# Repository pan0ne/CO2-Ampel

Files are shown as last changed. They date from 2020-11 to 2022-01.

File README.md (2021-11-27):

# DIY CO2-Messgerät / CO2-Ampel

Dieses Projekt zeigt den Bau einer CO2-Ampel.
Als Basis benutze ich einen **ESP8266 / ESP32 Mikrocontroller** und ein **MHZ-19b CO2-Sensor**. Zusätzlich kann ein **BME680 Luftqualitätssensor** angeschlossen werden, um die Messwerte zu präzisieren sowie **Neopixel (WS2812b)** und/oder ein **SSD1306 Display** zur visuellen Anzeige.  

**Messdaten**
- **Temperatur (C)**
- **Luftfeuchtigkeit (%)**
- **CO2 (ppm)**,
- **Luftdruck (hPa)**
- **Luftqualität (VOC, flüchtige organische Verbindungen)**.

Die **Sensordaten** können via **LoRa WAN** an das **thethingsnetwork.org** gesendet werden oder direkt per **WiFi**.
Zur **Analyse der Daten** werden diese an **thingsspeak.com** übertragen und grafisch aufbereitet. (Account nötig)
Bis auf den CO2-Sensor, der mit 5V betrieben wird, reicht für alles andere 3.3V. Der CO2-Sensor wird seriell über die RX/TX Pins abgefragt. Der Luftqualitätssensor kommuniziert über den i2c bus.

**Gehäuse**
- **Design**: TinkerCad.com
- **Download (.stl Format)**:
https://www.thingiverse.com/thing:4644826
- **Material**:   PLA (Sunlu), Holzoptik, carbonschwarz, transparent
- **Temperatur**: 195°C Noozle / Heizbett 58°
- **Einstellungen**: keine Stützstrukturen
- **Slicer**: Cura 4.x.x

**Bauanleitung**

Eine ***Bauanleitung*** mit allen Angaben von Druck der Bauteile über Verkabelung bis Programmierung befindet sich ***im Github Wiki***:

- https://github.com/pan0ne/CO2-Ampel/wiki/Home

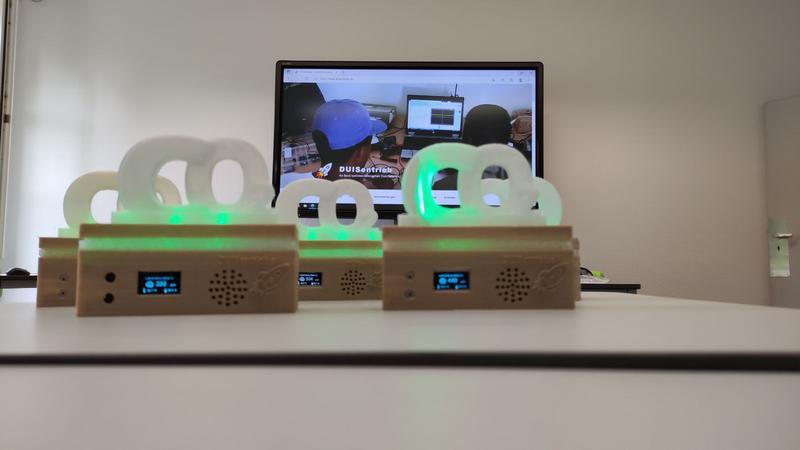
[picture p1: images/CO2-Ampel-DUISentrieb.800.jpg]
Verwendete Werkzeuge


[Weitere Fotos in der Galerie auf Thingiverse](https://www.thingiverse.com/thing:4644826)

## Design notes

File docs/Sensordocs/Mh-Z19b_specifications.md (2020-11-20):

**The MH-Z19B carbon dioxide gas sensor**

*Parameters:*

Product Model Number: MH-Z19B

Gas detection: carbon dioxide

Supply voltage: 4.5 ~ 5.5 V DC

Average current: <20mA (at 5V power supply)

Peak current: 150 mA (at 5 V supply)

Interface Level: 3.3V (5V compatible)

Measuring range: 0 ~ 10000ppm can be selected within the range

Warm-up time: 3 minutes

Response time: T90 <120s

Working temperature: 0 - 50 °C

Humidity: 0 to 95% RF (non-condensing)

Vin: positive power (Vin)

GND: Negative power supply (GND)

VO: Analog output

PWM: PWM

HD: HD (zero for school, low for more than 7 seconds)

Rx: TTL level data input for UART (RXD)

Tx: TTL data output with UART (TXD) level

Pin 1: Analogue output from

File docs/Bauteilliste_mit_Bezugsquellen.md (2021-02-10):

##Elektronische Bauteile / Einkaufsliste##

**Heltec Wifi LoRa v2 Microcontriller (ESP32)**
- Boardinformationen: https://heltec.org/project/wifi-lora-32/ 
- incl. Display SSD1306 (128x64, OLED), I2C 
- Quelle: https://www.az-delivery.de/products/nodemcu-esp32-mit-integrierten-oled-display?_pos=2&_sid=3fde67778&_ss=r (33.99€ DE Versand)

**Wifi Version ohne LoRaWAN**:
 - https://www.az-delivery.de/products/nodemcu (5,99€)
 - Display: https://www.conrad.de/de/p/joy-it-sbc-oled01-display-modul-2-4-cm-0-96-zoll-128-x-64-pixel-2176922.html (6,99€)

**Bosch BlueDot BME680 (Temp, VOC, Humidity, Air Pressure), I2C**
- https://www.bluedot.space/sensor-boards/bme680/
- Quelle: https://www.exp-tech.de/sensoren/temperatur/8371/bluedot-bme680-breakout-board-temperatur-feuchte-luftdruck-und-gas (21,40€ DE Versand)

- **Alternative BME680 (CJMCU) Sensor:** 
 - https://www.banggood.com/CJMCU-680-BME680-BOSCH-Temperature-And-Humidity-Pressure-Sensor-p-1268323.html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 (ca. 10€)
 - 
 
**MH-Z19B CO2 Sensor (RX, TX), Serial**
- Docs: https://www.winsen-sensor.com/d/files/infrared-gas-sensor/mh-z19b-co2-ver1_0.pdf
- Quelle: https://www.reichelt.de/infrarot-co2-sensor-mh-z19b-co2-mh-z19b-p266033.html (27,00€, Articel: CO2 MH-Z19B)
- Quelle: https://www.banggood.com/MH-Z19-MH-Z19B-Infrared-CO2-Sensor-Module-Carbon-Dioxide-Gas-Sensor-for-CO2-Monitor-0-5000ppm-MH-Z19B-NDIR-with-Pin-p-1693604.html (23€)

**Neopixel LED 1m Strip**
- Quelle: https://www.conrad.de/de/p/makerfactory-m5stack-neopixel-strip-mf-6324765-led-streifen-mit-stecker-buchse-3-5-v-526-mm-tape-cut-2108255.html (19,49€, Article: 2108255 - 62, DE Verkauf)
- Quelle (die günstige Variante): https://de.banggood.com/1M-WS2812-IC-SMD5050-Dream-Color-RGB-Non-Waterproof-LED-Strip-Light-Individual-Addressable-DC5V-p-1139749.html?ID=224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 (5,12€, Versand aus China oder Spanien) 
Quelle: https://www.banggood.com/4-PCS-PandaRC-5V-RGB-WS2812-LED-Strip-w-or-100mm-Cable-for-F3-F4-Flight-Controller-RC-Drone-FPV-Racing-p-1672588.html
(6€)
- https://www.banggood.com/Lantian-2-in-1-WS2812B-LED-And-5V-Active-Buzzer-For-FPV-NAZE32-Skyline32-Flight-Controller-p-1012950.html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
(8 x WS2812B LED And 5V Active Buzzer, ca 4€)

Sicher können hier auch andere Neopixelvarianten benutzt werden. Es gibt kleine 8 Pixelstreifen auch für 3 €uro im Netz zu finden.

**Batterie Modul 18650 V3 inkl. USB Kabel**
- Quelle (die günstige Variante): https://de.banggood.com/ESP32S-ESP32-0_5A-Micro-USB-Charger-Board-18650-Battery-Charging-Shield-without-Battery-p-1395271.html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 (3,24€ UK Versand)
- Quelle:  https://www.az-delivery.de/products/battery-expansion-shield-18650-v3-inkl-usb-kabel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 (7,47€ DE Verkauf)

**DuPont Cable with Connector (2x4Wire, 1x3Wire), Power Connector Cable for Heltec Microcontroller**
- Jumper Wire Kabel 40 STK. je 20 cm F2F Female to Female, Male-Female für Arduino und Raspberry Pi Breadboard
- https://www.az-delivery.de/products/40-stk-jumper-wire?_pos=9&_sid=12ce6cb8d&_ss=r (3,66€ DE Versand) 

**Gesamtkosten :  ca. 113€** (Shops innerhalb Europas)

**(direkt aus CN, Banggood, AliExpress oder Amazon Import: ~85,00€)**

**(Alternative Version: ESP8266: ~60,00€)**

**(direkt aus CN, Banggood, AliExpress oder Amazon Import: 40 - 50€)**

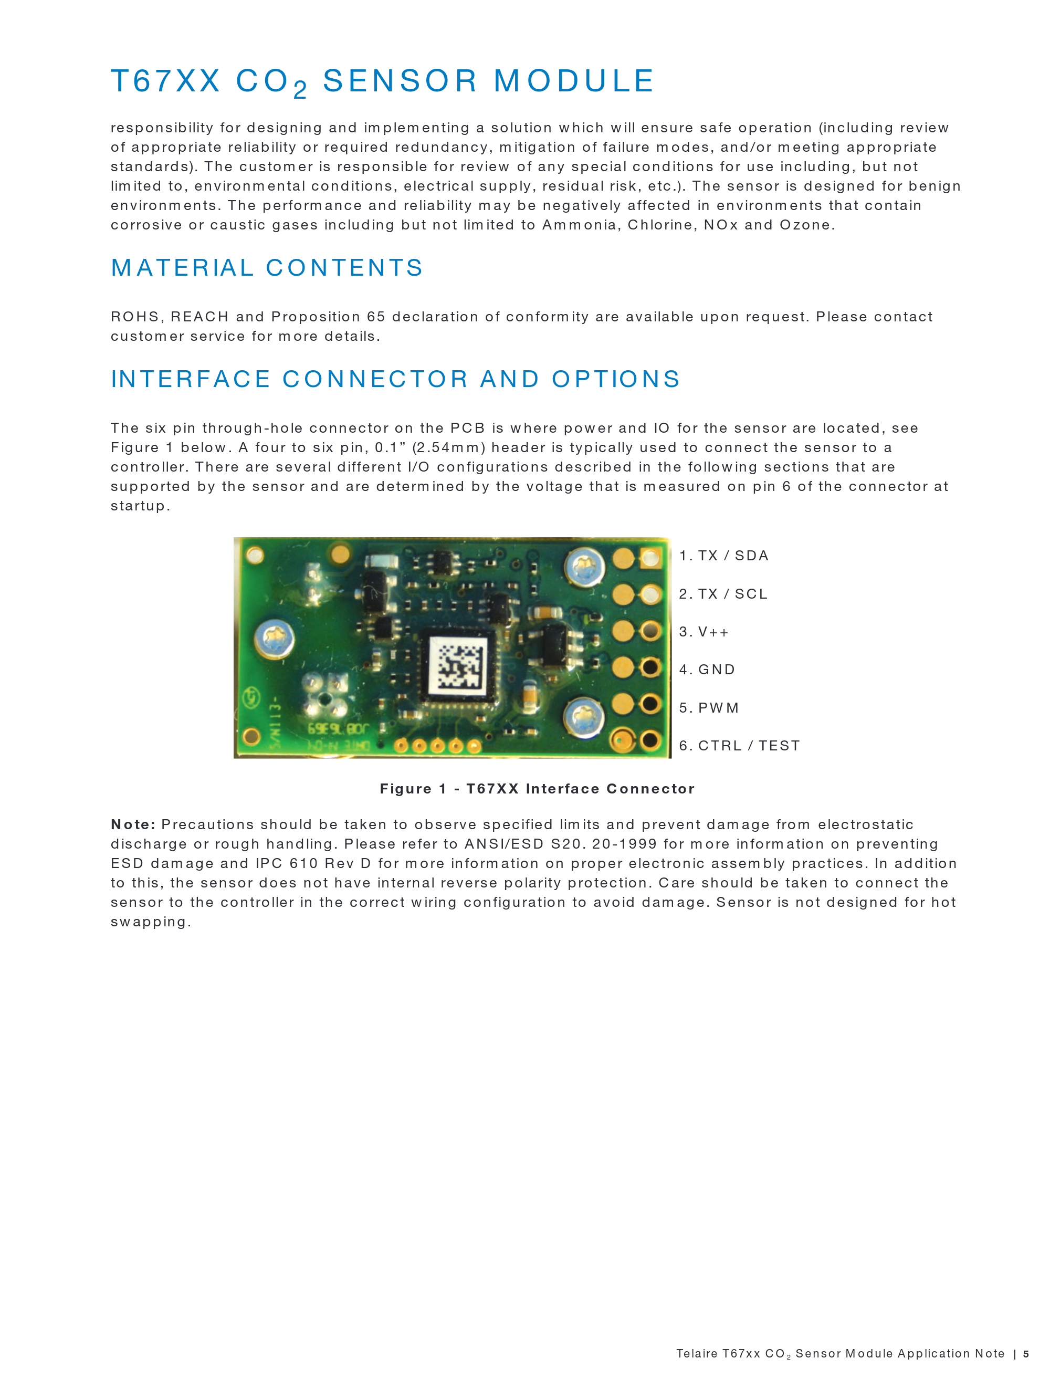
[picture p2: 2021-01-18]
docs/MCU-Sensor_Pinout/Telaire_T67xx_MiniCO2Sensor.png

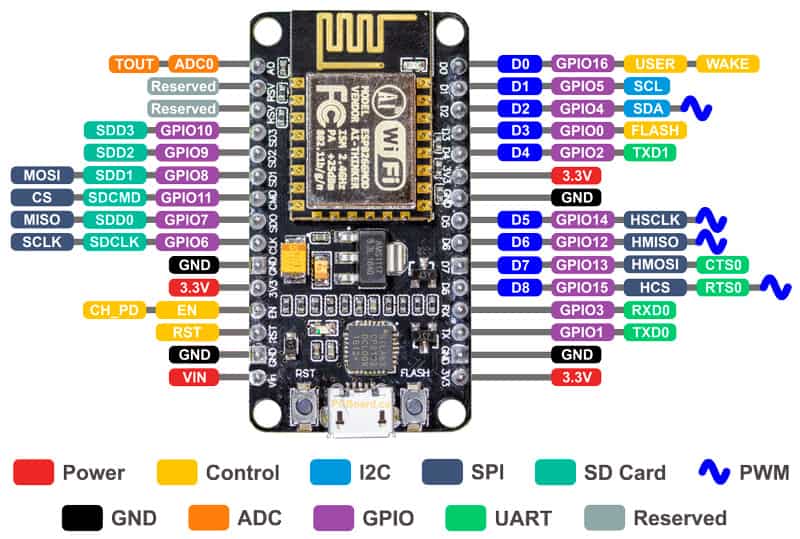
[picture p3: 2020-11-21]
docs/MCU-Sensor_Pinout/nodemcu-pinout-functions.jpg

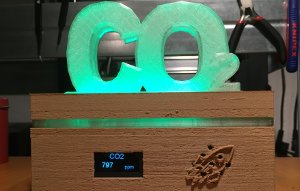
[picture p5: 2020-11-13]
images/CO2-Meter2.jpg

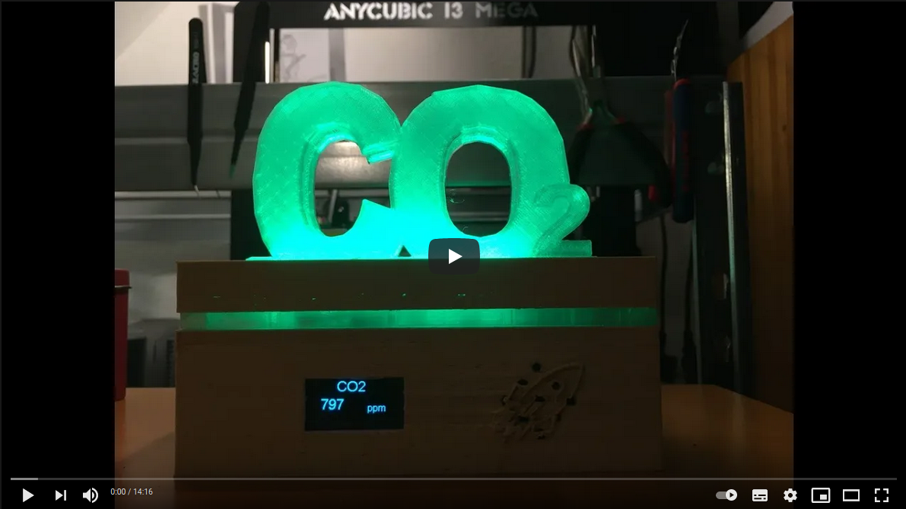
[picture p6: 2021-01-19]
images/CO2-Ampel_VideoCoverImage.png

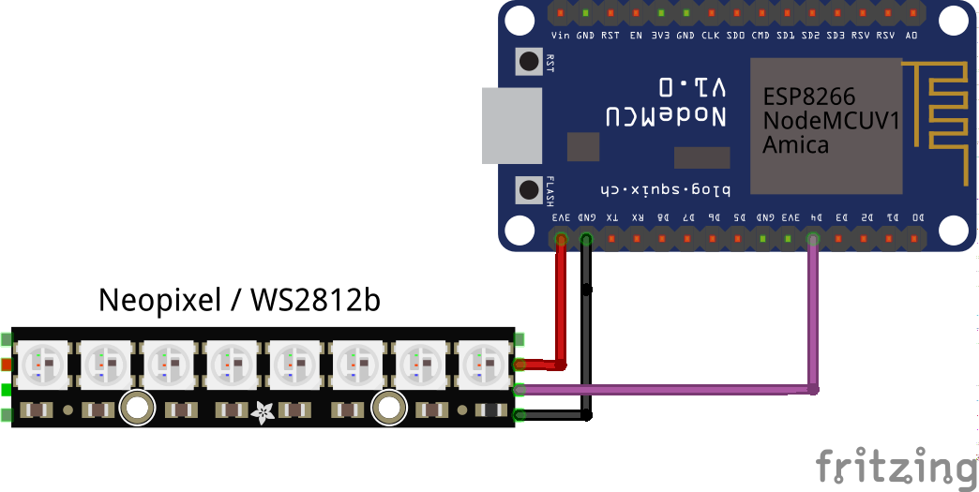
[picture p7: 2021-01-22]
docs/Anschlussdiagramme/CO2-Ampel_Anschluss_Esp8266-Neopixel.png

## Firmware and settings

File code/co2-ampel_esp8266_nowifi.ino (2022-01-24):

/*
  ESP8266 CO2 Ampel noWiFi Version
  Author: Pan0ne
  Date/Version: 202201241800
  Libraries:
    Arduino.h>           -> https://github.com/esp8266/Arduino
    ArduinoJson.h        -> https://github.com/bblanchon/ArduinoJson
    Wire.h               -> http://librarymanager#Wire
    SoftwareSerial.h     -> http://librarymanager#SoftSerial
    Adafruit_NeoPixel.h  -> http://librarymanager#Adafruit_NeoPixel
    SSD1306Wire.h        -> http://librarymanager#SSD1306_esp8266_oled_driver
    Adafruit_Sensor.h    -> http://librarymanager#Adafruit_Sensor
    MHZ19.h              -> http://librarymanager#MH-Z19 (by J. Dempsey)
    Adafruit_BME680.h    -> http://librarymanager#Adafruit_BME680
    
  Include: 
    images.h             -> Create new tab in Arduino IDE and copy example from github if not there
    config.h             -> Create new tab in Arduino IDE and copy example from github if not there
*/

#include <Arduino.h>            

#ifdef __AVR__
  #include <avr/power.h>
#endif

#include <ArduinoJson.h>
#include <Wire.h>              
#include "images.h"            
#include "config.h"            
#include <SoftwareSerial.h>     
#include <Adafruit_NeoPixel.h>  
#include "SSD1306Wire.h"        
#include <Adafruit_Sensor.h>   

#if SENSOR_MHZ19B
  #include "MHZ19.h"           
#endif

#if SENSOR_BME680
  #include "Adafruit_BME680.h"  
#endif

/***************************************************************************
  SSD1606 Display OLED Pins -> ESP8266_amica
  OLED_SDA -- D2
  OLED_SCL -- D1
  OLED_RST -- RST
 ****************************************************************************/
SSD1306Wire display(0x3c, SDA, SCL);
/***************************************************************************
  CO2 Sensor -   MH-Z19b Pins -> ESP8266_amica
  MH-Z19b_RX - D6 Pin
  MH-Z19b_TX - D7 Pin
 ****************************************************************************/
unsigned long getDataTimer = 0;
MHZ19 myMHZ19;          // Constructor for library
SoftwareSerial mySerial(RX_PIN, TX_PIN);                   // (Uno example) create device to MH-Z19 serial
//HardwareSerial mySerial(1);
int8_t Temp;
int CO2;
/***************************************************************************
 Button handler (FlashButton als normalen Inputbutton verwenden)
 ****************************************************************************/

void IRAM_ATTR handleInterrupt() {
  dMode++;
}
/***************************************************************************
  BME 680 Sensor / Pins -> ESP8266_amica
  SDA - D2 (GPIO 2)
  SCL - D1 (GPIO 1) 
 ****************************************************************************/
#define SEALEVELPRESSURE_HPA (1013.25)
Adafruit_BME680 bme; // I2C

float hum_weighting = 0.25; // so hum effect is 25% of the total air quality score
float gas_weighting = 0.75; // so gas effect is 75% of the total air quality score

int   humidity_score, gas_score;
float gas_reference = 2500;
float hum_reference = 40;
int   getgasreference_count = 0;
int   gas_lower_limit = 10000;  // Bad air quality limit
int   gas_upper_limit = 300000; // Good air quality limit
String  air_quality;
/***************************************************************************
    Logo "co2a_logo" -> images.h
    Duisentrieb Logo und Schriftzug
 ****************************************************************************/
void logo()
{
  display.clear();
  display.drawXbm(85, 2, co2a_logo_width, co2a_logo_height, co2a_logo);
  display.setFont(ArialMT_Plain_10);
  display.drawString(15, 15, "DUISentrieb");
  delay(1000);
  display.setFont(ArialMT_Plain_24);
  display.drawString(2, 35, "CO2 Meter");
  display.display();
  delay(6000);
}
/***************************************************************************  
  Neopixel / Pin -> ESP8266_amica
  Di - D5 (GPIO 25)
 ****************************************************************************/
Adafruit_NeoPixel pixels(atof(pixel), PIN, NEO_GRB + NEO_KHZ800);
#define DELAYVAL 500 // Time (in milliseconds) to pause between pixels

// Rainbow cycle along whole strip. Pass delay time (in ms) between frames.
void rainbow(int wait) {
  //pixels.setBrightness(atof(pixel_brightness));
  for (long firstPixelHue = 0; firstPixelHue < 5 * 65536; firstPixelHue += 256) {
    for (int i = 0; i < pixels.numPixels(); i++) { // For each pixel in strip...
      // (strip.numPixels() steps):
      int pixelHue = firstPixelHue + (i * 65536L / pixels.numPixels());
      pixels.setPixelColor(i, pixels.gamma32(pixels.ColorHSV(pixelHue)));
    }
    pixels.show(); // Update strip with new contents
    delay(wait);  // Pause for a moment
  }
}

void colorWipe(uint32_t color, int wait) {
  pixels.setBrightness(atof(pixel_brightness));
  for (int i = 0; i < pixels.numPixels(); i++) { // For each pixel in strip...
    pixels.setPixelColor(i, color);         //  Set pixel's color (in RAM)
    pixels.show();                          //  Update strip to match
    delay(wait);                           //  Pause for a moment
  }  
}
/***************************************************************************
    Setup
 ****************************************************************************/
void setup()
{
  Serial.begin(9600);
  
  #if defined (__AVR_ATtiny85__)
  if (F_CPU == 16000000) clock_prescale_set(clock_div_1);
  #endif
  
  pixels.begin();
  pixels.show();  // Turn OFF all pixels ASAP
  pixels.setBrightness(100);
  rainbow(40);  //colorWipe(pixels.Color(255,   0,   0), 150); // Red

  Wire.begin();
  bme.begin();

    if (!bme.begin()) {
      #if DEBUG
      Serial.println("Could not find a valid BME680 sensor, check wiring!");
      #endif
    } else {
      #if DEBUG
      Serial.println("Found a sensor");
      #endif
    }

  // Set up oversampling and filter initialization
  bme.setTemperatureOversampling(BME680_OS_8X);
  bme.setHumidityOversampling(BME680_OS_2X);
  bme.setPressureOversampling(BME680_OS_4X);
  bme.setIIRFilterSize(BME680_FILTER_SIZE_3);
  bme.setGasHeater(320, 150); // 320*C for 150 ms
  delay(500);
  bme.performReading();
  delay(500);
  GetGasReference();

  //SSD1306_SWITCHCAPVCC = generate display voltage from 3.3V internally

  // Initialising the UI will init the display too.
  // Show initial display buffer contents on the screen --
  // the library initializes this with an Adafruit splash screen.
  display.init();
  display.flipScreenVertically();
  display.setFont(ArialMT_Plain_10);
  display.clear();
  delay(2000); // Pause for 2 seconds
  display.clear(); // Clear the buffer

  logo();

  display.clear();
  display.setTextAlignment(TEXT_ALIGN_CENTER);
  display.setFont(ArialMT_Plain_16);
  display.drawString(60, 10, "CO2 Meter");  
  display.drawString(60, 35, "Offline Mode");
  display.display();

  mySerial.begin(BAUDRATE);          // Uno Example: Begin Stream with MHZ19 baudrate
  myMHZ19.begin(mySerial);
  myMHZ19.autoCalibration(MHZ_CLB_MODE);   // Turn auto calibration ON (OFF autoCalibration(false))
 
  pinMode(FlashButtonPIN, INPUT_PULLUP);
  attachInterrupt(digitalPinToInterrupt(FlashButtonPIN), handleInterrupt, FALLING);

}


void loop()
{
  readMHZ19b();
  humidity_score = GetHumidityScore();
  gas_score      = GetGasScore();
  //Combine results for the final IAQ index value (0-100% where 100% is good quality air)
  float air_quality_score = humidity_score + gas_score;
  if ((getgasreference_count++) % 5 == 0) GetGasReference();
  air_quality = CalculateIAQ(air_quality_score);  
  display.clear();
  display.setTextAlignment(TEXT_ALIGN_CENTER);
  display.setFont(ArialMT_Plain_10);
  display.drawString(62, 1, String(air_quality));
  display.drawXbm(12, 14, co2_sym_width, co2_sym_height, co2_sym);
  display.setTextAlignment(TEXT_ALIGN_LEFT);
  display.setFont(ArialMT_Plain_24);
  display.drawString(50, 15, String(CO2));
  display.setFont(ArialMT_Plain_10);
  display.drawString(100, 27," ppm" );
  display.setFont(ArialMT_Plain_10);
  display.drawXbm(2, 46, temperature_icon_width, temperature_icon_height, temperature_icon);
  display.drawString(20, 48, String(bme.readTemperature() + temp_adjust, 1)  + " °C");
  display.setTextAlignment(TEXT_ALIGN_RIGHT);
  display.setFont(ArialMT_Plain_10);
  //display.drawString(120, 50, String(Temp) + "°C");
  display.drawXbm(80, 46, humidity_icon_width, humidity_icon_height, humidity_icon);
  display.drawString(128, 48, String(bme.readHumidity(), 1)  + " %");
  display.display();
  co2Warnung();
   if (dMode != last_dMode) { 
            display.clear();
            display.setTextAlignment(TEXT_ALIGN_CENTER);
            display.setFont(ArialMT_Plain_24);
            display.drawString(60, 20, "Kalibrierung \n gestartet");
            delay(1000);  
            display.clear();  
            display.setFont(ArialMT_Plain_24);
            display.drawString(60, 1, "Achtung!");
            display.setFont(ArialMT_Plain_10);
            display.drawString(60, 25, "Gerät sollte vorher \n min. 10 Minuten an der \n frischen Luft stehen!");
            display.display(); 
            myMHZ19.calibrateZero();
            delay(5000);
            display.clear();
            display.drawString(60, 20, "Kalibrierung \n erfolgreich!");
            display.display();
            delay(1000);    
            last_dMode = dMode;
     }
}

void readMHZ19b()
{
  const int INTERVAL = 3000;
  static unsigned long previousMillis;
  static int counter;

  if (millis() - previousMillis > INTERVAL)
  {
    previousMillis = millis();
    CO2 = myMHZ19.getCO2();           // Request CO2 (as ppm)
    Temp = myMHZ19.getTemperature();   // Request Temperature (as Celsius)
    #if DEBUG
    Serial.print(F("CO2 und Temperatur lesen: "));
    Serial.println(counter);    
    Serial.print(F("CO2: "));
    Serial.println(CO2);    
    Serial.print(F("MHZ Temp: "));
    Serial.println(Temp);
    #endif 
    counter++;
     if (counter > 10){
       counter = 0;
      }
      return;
  }
}

/*  Neopixel colored by CO2 Level
 *  CO2 < 850ppm -> color is green 
 *  over 850ppm to 1200ppm -> color is yellow
 *  above 1600 ppm orange, then red or rainbow
 */
void co2Warnung()
{
  if(CO2 < 850) {
    colorWipe(pixels.Color(  0, 255,   0), 30); // green
  }else{
  if(CO2 < 1200) {
    colorWipe(pixels.Color(  150, 150,   0), 70); // yellow
  }else{
  if(CO2 < 1600) {
     colorWipe(pixels.Color(  255, 71,   0), 100); // orange
  }else{    
      rainbow(10);  // Rainbox
      //colorWipe(pixels.Color(255,   0,   0), 150); // Red
      }
  }
  }
}

void GetGasReference() {
  // Now run the sensor for a burn-in period, then use combination of relative humidity and gas resistance to estimate indoor air quality as a percentage.
  #if DEBUG
  Serial.println("Getting a new gas reference value");
  #endif
  int readings = 10;
  for (int i = 1; i <= readings; i++) { // read gas for 10 x 0.150mS = 1.5secs
    gas_reference += bme.readGas();
  }
  gas_reference = gas_reference / readings;
  #if DEBUG
  Serial.println("Gas Reference = "+String(gas_reference,3));
  #endif
}

String CalculateIAQ(int score) {
  String IAQ_text = "Luft ";
  score = (100 - score) * 5;
  if      (score >= 301)                  IAQ_text += "ist gefährlich";
  else if (score >= 201 && score <= 300 ) IAQ_text += "ist sehr ungesund";
  else if (score >= 151 && score <= 200 ) IAQ_text += "ist ungesund";
  else if (score >= 101 && score <= 150 ) IAQ_text += "noch OK";
  else if (score >= 51 && score <= 100 ) IAQ_text += "ist gut";
  else if (score >=  00 && score <= 50 ) IAQ_text += "ist frisch";
  //display.setTextAlignment(TEXT_ALIGN_CENTER);
  //display.setFont(ArialMT_Plain_10);
  //display.drawString(60, 59, "IAQ Score = " + String(score) + ", ");
  return IAQ_text;
}

int GetHumidityScore() {  //Calculate humidity contribution to IAQ index
  float current_humidity = bme.readHumidity();
  if (current_humidity >= 38 && current_humidity <= 42) // Humidity +/-5% around optimum
    humidity_score = 0.25 * 100;
  else
  { // Humidity is sub-optimal
    if (current_humidity < 38)
      humidity_score = 0.25 / hum_reference * current_humidity * 100;
    else
    {
      humidity_score = ((-0.25 / (100 - hum_reference) * current_humidity) + 0.416666) * 100;
    }
  }
  return humidity_score;
}

int GetGasScore() {
  //Calculate gas contribution to IAQ index
  gas_score = (0.75 / (gas_upper_limit - gas_lower_limit) * gas_reference - (gas_lower_limit * (0.75 / (gas_upper_limit - gas_lower_limit)))) * 100.00;
  if (gas_score > 75) gas_score = 75; // Sometimes gas readings can go outside of expected scale maximum
  if (gas_score <  0) gas_score = 0;  // Sometimes gas readings can go outside of expected scale minimum
  return gas_score;
}

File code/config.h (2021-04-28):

/***************************************************************************
                          ESP8266 Wifi Controller
                   Voreinstellungen und Verbindungsdaten
 ****************************************************************************/
#define SECRET_SSID "MySSID"    // SSID des WLAN
#define SECRET_PASS "MyPassword"  // PSW 

#define SECRET_CH_ID 000000     // thingspeak channel number
#define SECRET_WRITE_APIKEY "XYZ"   // thingspeak channel write API Key

/***************************************************************************
                         ESP32 HelTec LoRa Controller
    Go to your TTN console register a device then the copy fields
 ****************************************************************************/
const char* devEui = "xxxxxxx"; // Change to TTN Device EUI
const char* appEui = "xxxxxxx"; // Change to TTN Application EUI
const char* appKey = "xxxxxxx"; // Chaneg to TTN Application Key
#define BAND    868E6  //you can set band here directly,e.g. 868E6,915E6

/***************************************************************************
                          CO2 Sensor - Einstellungen  
 Die Kallibrierung sollte immer an der frischen Luft stattfinden. 
 Zuerst 10 Minuten lang stehen lassen und dann Knopf drücken.                         
 ****************************************************************************/
#define RX_PIN 13       // Rx pin (D7) which the MHZ19 Tx pin is attached to
#define TX_PIN 12       // Tx pin (D8) which the MHZ19 Rx pin is attached to
#define BAUDRATE 9600   // Device to MH-Z19 Serial baudrate (should not be changed)
#define MHZ_RANGE 5000  // Sensibilität der Messungen, bis 2000ppm, bis 5000ppm, bis 10000ppm
#define FlashButtonPIN 0 // Der Flash Button des NodeMCU Amica kallibriert die C02 Ampel und setzt den Wert zurück auf 400ppm. 
int dMode = 0;
int last_dMode = 0;


/***************************************************************************
                          Temperaturwertkorrektur 
Temperaturwert des BME680 korrigieren. 
Der Wert kann positiv und negativ sein. Zum Beispiel 2 oder -2                        
 ****************************************************************************/
int temp_adjust = 0;

/***************************************************************************
                Neopixel - Anzahl, Pin, Helligkeit
****************************************************************************/
#define PIN       2     // Pin - auf dem Heltec LoRa Wifi v2 ist es Pin 25
#define NUMPIXELS 4     // Anzahl der Pixel

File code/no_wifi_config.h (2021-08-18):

// Use this file to store all of the private credentials 
// and connection details

#define DEBUG true
#define SENSOR_MHZ19B true 
#define SENSOR_BME680 true
#define SENSOR_BME280 false

// CO2 Sensor - Einstellungen der Pins
#define RX_PIN 13       // Rx pin (D7) which the MHZ19 Tx pin is attached to
#define TX_PIN 12       // Tx pin (D8) which the MHZ19 Rx pin is attached to
#define BAUDRATE 9600   // Device to MH-Z19 Serial baudrate (should not be changed)
#define MHZ_RANGE 5000  // Sensibilität der Messungen, bis 2000ppm, bis 5000ppm, bis 10000ppm
#define MHZ_CLB_MODE

// Der Flash Button des NodeMCU Amica kallibriert die C02 Ampel und setzt den Wert zurück auf 400ppm. 
// Die Kallibrierung sollte immer an der frischen Luft stattfinden. 10 Minuten lang stehen lassen und dann Knopf drücken.
#define FlashButtonPIN 0

// Neopixel - Anzahl der Pixel, Helligkeit, Pin
#define PIN       2 // Pin - auf dem Heltec LoRa Wifi v2 ist es Pin 25

// Battery voltage resistance
#define BAT_RES_VALUE_GND 20.0
#define BAT_RES_VALUE_VCC 10.0
#define REFERENCE_VCC 3.3

//define your default values here, if there are different values in config.json, they are overwritten.
char pixel[3]  = "3";
char pixel_brightness[5] = "200";
char callibration_mode[6] = "false";

// Temperaturwert des BME680 korrigieren. Der Wert kann positiv und negativ sein. Zum Beispiel 2 oder -2
int temp_adjust = 0;

// Init manual calibration mode
int dMode = 0;
int last_dMode = 0;

// set PushButton pin number
//const int BUTTON_PIN = 0;

int buttonState;

unsigned long timePress = 0;
unsigned long timePressLimit = 0;
int clicks = 0;

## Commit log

2020-11-13 Create co2-ampel.ino
    CO2 Ampel Arduino Sketch upload
2020-11-21 Create config.h
    Anmeldeinformationen für WiFi und Thingspeak ausgelagert. Nur in esp8266 Version
2020-11-22 Logo geändert und ssd1306 library geändert.
    ssd1306wire.h in, adafruit_ssd1306.h out
    Sketch an die neue lib angepasst
2020-11-22 Touch Button Pin korrigiert
2020-11-22 Wiederhergestellt für ESP32
2020-11-23 Neues Schema für ESP8266 Variante der CO2 Ampel
2020-11-23 Add Info zu Boardmanger für ESP8266
2021-01-06 Anpassungen der Temperaturwerte BME680
2021-01-19 Text überarbeit und gekürzt
2021-01-19 Fritzing Anschlusskizzen und Modelle für Fritzing
    [CO2Ampel.fzz]
2021-01-19 Bauteil für NodeMCU hinzugefügt und Bezeichnungen angepasst
2021-01-19 Neue Modelle für Batteriehalterung und SSD1306 Display
2021-01-19 Alternativer BME680 Sensor für VOC.Keine Temperaturmessung möglich
2021-01-19 Umstrukturierung nach Pinout-Diagrammen und Datenblätter
2021-01-19 Anschlussfotos NodeMCU und SSD1306 OLED Display
2021-01-19 Tabellen zur Verkabelung und Angaben über Boardmanager und Librarys ins Wiki verschoben und verlinkt
2021-01-19 Ordnerbezeichnung angepasst
    [CO2Ampel.fzz]
2021-01-19 Umbenannt- Das ist der Amica :-)
2021-01-19 Readme verkleinert und Textteile ins Wiki ausgelagert
2021-01-19 optisch angepasstes Modell des Sensors
2021-01-21 Fritzing für Amica ergänzt
    [CO2-Ampel_Amica.fzz]
2021-01-22 Weitere Anschlussdiagramme hinzugefügt.
    [CO2-Ampel_Amica.fzz, CO2-Ampel_Anschluss_Esp8266-BME680.fzz, CO2-Ampel_Anschluss_Esp8266-MH-Z19b.fzz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]
2021-01-27 Code kommentiert
    Bei der Ausgabe von Messwerten auf dem Display können verschiedene Temperaturmesswerte (Temp BME680/Temp MHZ-19b) ausgegeben werden. Diese stelle habe ich etwas genauer im Code kommentiert.
2021-01-27 Zeile gelöscht
    Das Auslesen der Temperatur ist an dieser Stelle überflüssig, weil der Wert des CO2 Sensors schon über readMHZ19b() an Temp übergeben wird. Danke Dieter!
2021-01-27 CO2 Sensor: autoCalibration(false)
    autoCalibration(false) eingestellt statt auskommentiert
2021-01-28 Stromversorgung vom BME nach unten und vom Neopixel nach oben verlegt
    [CO2-Ampel_Amica.fzz, CO2-Ampel_Anschluss_Esp8266Neopixel-.fzz]
2021-02-10 Zeile 237 Temperaturwerte anpassen
2021-02-10 Amica Flashbutton eingebaut
    - Der Flashbutton kalibriert die Ampel auf 400ppm
    - Statische Variablen für Anzah der Neopixel und Sensorpins in config.h ausgelagert
2021-02-11 Fotocollagen hochgeladen
    Die Fotos dienen der Bauanleitung im Wiki
2021-02-11 Versionsnummer und Header angepasst
2021-04-06 Add WiFiManager Library
    Die WifiManager Bibliothek ermöglicht eine schnelle Anbindung in das lokale WLAN ohne, dass das Sketch neu hochgeladen werden muss. Bei erster Inbetriebname stellt der ESP8266 einen offenen AccessPoi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
2021-04-26 Bugfix: Comment out Function getBatteryVoltage()
    Außerdem habe ich ein paar Hinweise zu config.h und images.h hinzugefügt.
    Autokallibrierung auf true voreingestellt
    [co2-ampel_esp8266.ino]
2021-04-28 Anzeige der Batterieladung auskommentiert
2022-01-23 Update co2-ampel_esp8266_nowifi.ino
    In Zeile 212 die Ausgabe der Luftqualität auskommentiert.
2022-01-24 Luftqualitätswerte angepasst
    Ausgabe der Luftqualitätswerte angepasst ab Zeile 347. Wie in diesem Beispiel -> https://steinlaus.de/stinkt-das-hier-teil-1-mit-dem-bosch-bme680/
    Die Zeile für die Ausgabe der Werte auf dem Display, ab 212, wurde wieder aktiviert.
2022-01-24 Header aktualisiert
    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
2022-01-24 unbenutzte Funktionen entfernt
    Die ungenutzen Funktionen im Code für die Audiosignalausgabe und die Anzeige des Batteriestatus wurden entfernt da diese nicht benutzt werden.
